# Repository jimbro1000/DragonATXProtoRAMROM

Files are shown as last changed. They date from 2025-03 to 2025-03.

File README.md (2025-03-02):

# Dragon 32 ATX Prototype RAM and ROM

This repository contains the KiCad project files
to produce the RAM and ROM component board for my
ATX Prototype backplane.

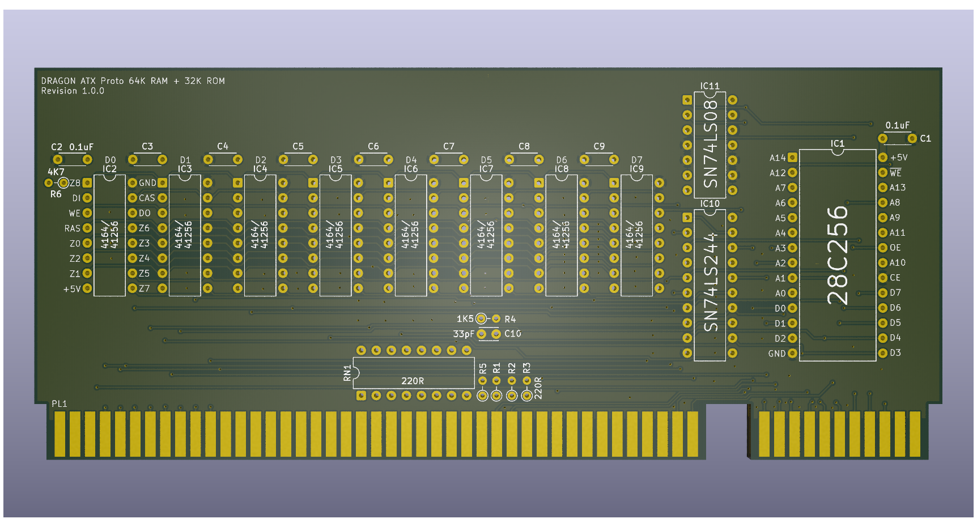
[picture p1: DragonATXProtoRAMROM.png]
Render of PCB top


This design requires the ATX backplane board in order 
to operate
See https://github.com/jimbro1000/DragonATXProto

## Notes

Revision 1 of the board contains a design using 
conventional DRAM, either 64k or 256k. Revision 2 will 
use SRAM.

Revision 3 will contain just a Flash ROM for use with
the FPGA board on the backplane as this carries a
large volume of RAM onboard.

This design has been completed using KiCad 9. Earlier
versions of KiCad are not compatible.

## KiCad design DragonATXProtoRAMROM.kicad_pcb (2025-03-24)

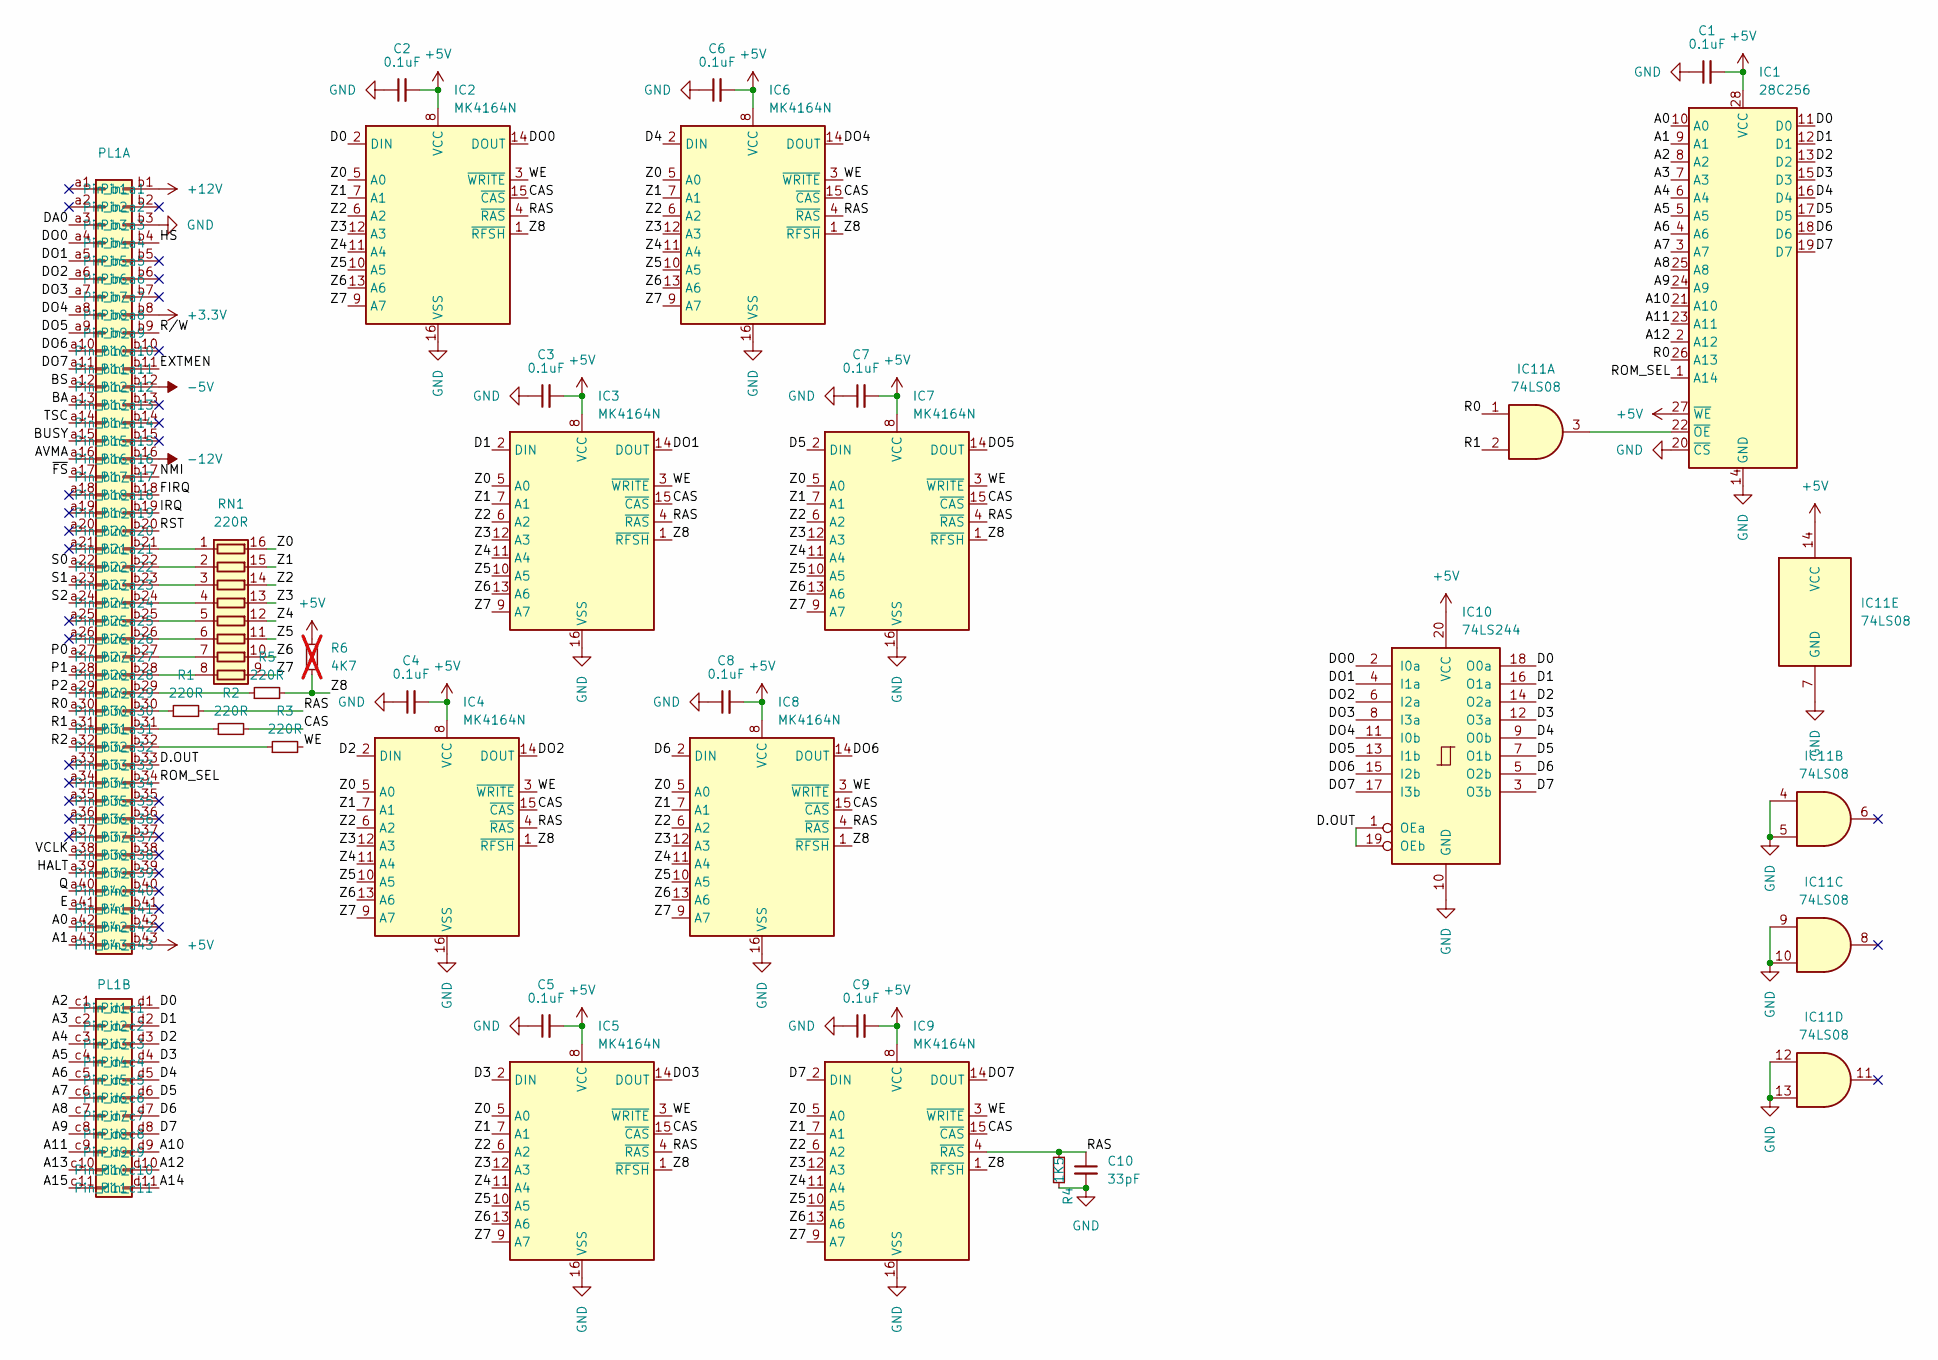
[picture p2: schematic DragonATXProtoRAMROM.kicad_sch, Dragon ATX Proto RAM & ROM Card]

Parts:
C1, C2, C3, C4, C5, C6, C7, C8, C9: 0.1uF; C_Disc_D4.3mm_W1.9mm_P5.00mm; DigiKey BC1101CT-ND
C10: 33pF; C_Disc_D3.0mm_W2.0mm_P2.50mm; DigiKey BC1007CT-ND
IC1: 28C256; DIP-28_W15.24mm
IC2, IC3, IC4, IC5, IC6, IC7, IC8, IC9: MK4164N; DIP-16_W7.62mm
IC10: 74LS244; DIP-20_W7.62mm
IC11: 74LS08; DIP-14_W7.62mm
PL1: Card_Edge
R1, R2, R3, R5: 220R; R_Axial_DIN0204_L3.6mm_D1.6mm_P2.54mm_Vertical
R4: 1K5; R_Axial_DIN0204_L3.6mm_D1.6mm_P2.54mm_Vertical; DigiKey CF14JT1K50CT-ND
R6: 4K7; R_Axial_DIN0204_L3.6mm_D1.6mm_P2.54mm_Vertical; not fitted
RN1: 220R; DIP-16_W7.62mm

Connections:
+3.3V: PL1.b8
+5V: C1.2, C2.2, C3.2, C4.2, C5.2, C6.2, C7.2, C8.2, C9.2, IC1.27 (~WE), IC1.28 (VCC), IC2.8 (VCC), IC3.8 (VCC), IC4.8 (VCC), IC5.8 (VCC), IC6.8 (VCC), IC7.8 (VCC), IC8.8 (VCC), IC9.8 (VCC), IC10.20 (VCC), IC11.14 (VCC), PL1.b43, R6.2
+12V: PL1.b1
-5V: PL1.b12
-12V: PL1.b16
/A0: IC1.10 (A0), PL1.a42
/A1: IC1.9 (A1), PL1.a43
/A2: IC1.8 (A2), PL1.c1
/A3: IC1.7 (A3), PL1.c2
/A4: IC1.6 (A4), PL1.c3
/A5: IC1.5 (A5), PL1.c4
/A6: IC1.4 (A6), PL1.c5
/A7: IC1.3 (A7), PL1.c6
/A8: IC1.25 (A8), PL1.c7
/A9: IC1.24 (A9), PL1.c8
/A10: IC1.21 (A10), PL1.d9
/A11: IC1.23 (A11), PL1.c9
/A12: IC1.2 (A12), PL1.d10
/A13: PL1.c10
/A14: PL1.d11
/A15: PL1.c11
/AVMA: PL1.a16
/BA: PL1.a13
/BS: PL1.a12
/BUSY: PL1.a15
/CAS: IC2.15 (~CAS), IC3.15 (~CAS), IC4.15 (~CAS), IC5.15 (~CAS), IC6.15 (~CAS), IC7.15 (~CAS), IC8.15 (~CAS), IC9.15 (~CAS), R2.2
/D0: IC1.11 (D0), IC2.2 (DIN), IC10.18 (O0a), PL1.d1
/D1: IC1.12 (D1), IC3.2 (DIN), IC10.16 (O1a), PL1.d2
/D2: IC1.13 (D2), IC4.2 (DIN), IC10.14 (O2a), PL1.d3
/D3: IC1.15 (D3), IC5.2 (DIN), IC10.12 (O3a), PL1.d4
/D4: IC1.16 (D4), IC6.2 (DIN), IC10.9 (O0b), PL1.d5
/D5: IC1.17 (D5), IC7.2 (DIN), IC10.7 (O1b), PL1.d6
/D6: IC1.18 (D6), IC8.2 (DIN), IC10.5 (O2b), PL1.d7
/D7: IC1.19 (D7), IC9.2 (DIN), IC10.3 (O3b), PL1.d8
/D.OUT: IC10.1 (OEa), IC10.19 (OEb), PL1.b33
/DA0: PL1.a3
/DO0: IC2.14 (DOUT), IC10.2 (I0a), PL1.a4
/DO1: IC3.14 (DOUT), IC10.4 (I1a), PL1.a5
/DO2: IC4.14 (DOUT), IC10.6 (I2a), PL1.a6
/DO3: IC5.14 (DOUT), IC10.8 (I3a), PL1.a7
/DO4: IC6.14 (DOUT), IC10.11 (I0b), PL1.a8
/DO5: IC7.14 (DOUT), IC10.13 (I1b), PL1.a9
/DO6: IC8.14 (DOUT), IC10.15 (I2b), PL1.a10
/DO7: IC9.14 (DOUT), IC10.17 (I3b), PL1.a11
/E: PL1.a41
/EXTMEN: PL1.b11
/FIRQ: PL1.b18
/HALT: PL1.a39
/HS: PL1.b4
/IRQ: PL1.b19
/NMI: PL1.b17
/P0: PL1.a27
/P1: PL1.a28
/P2: PL1.a29
/Q: PL1.a40
/R0: IC1.26 (A13), IC11.1, PL1.a30
/R1: IC11.2, PL1.a31
/R2: PL1.a32
/RAS: C10.1, IC2.4 (~RAS), IC3.4 (~RAS), IC4.4 (~RAS), IC5.4 (~RAS), IC6.4 (~RAS), IC7.4 (~RAS), IC8.4 (~RAS), IC9.4 (~RAS), R1.2, R4.2
/ROM_SEL: IC1.1 (A14), PL1.b34
/RST: PL1.b20
/R/W: PL1.b9
/S0: PL1.a22
/S1: PL1.a23
/S2: PL1.a24
/TSC: PL1.a14
/VCLK: PL1.a38
/WE: IC2.3 (~WRITE), IC3.3 (~WRITE), IC4.3 (~WRITE), IC5.3 (~WRITE), IC6.3 (~WRITE), IC7.3 (~WRITE), IC8.3 (~WRITE), IC9.3 (~WRITE), R3.2
/Z0: IC2.5 (A0), IC3.5 (A0), IC4.5 (A0), IC5.5 (A0), IC6.5 (A0), IC7.5 (A0), IC8.5 (A0), IC9.5 (A0), RN1.16 (R1.2)
/Z1: IC2.7 (A1), IC3.7 (A1), IC4.7 (A1), IC5.7 (A1), IC6.7 (A1), IC7.7 (A1), IC8.7 (A1), IC9.7 (A1), RN1.15 (R2.2)
/Z2: IC2.6 (A2), IC3.6 (A2), IC4.6 (A2), IC5.6 (A2), IC6.6 (A2), IC7.6 (A2), IC8.6 (A2), IC9.6 (A2), RN1.14 (R3.2)
/Z3: IC2.12 (A3), IC3.12 (A3), IC4.12 (A3), IC5.12 (A3), IC6.12 (A3), IC7.12 (A3), IC8.12 (A3), IC9.12 (A3), RN1.13 (R4.2)
/Z4: IC2.11 (A4), IC3.11 (A4), IC4.11 (A4), IC5.11 (A4), IC6.11 (A4), IC7.11 (A4), IC8.11 (A4), IC9.11 (A4), RN1.12 (R5.2)
/Z5: IC2.10 (A5), IC3.10 (A5), IC4.10 (A5), IC5.10 (A5), IC6.10 (A5), IC7.10 (A5), IC8.10 (A5), IC9.10 (A5), RN1.11 (R6.2)
/Z6: IC2.13 (A6), IC3.13 (A6), IC4.13 (A6), IC5.13 (A6), IC6.13 (A6), IC7.13 (A6), IC8.13 (A6), IC9.13 (A6), RN1.10 (R7.2)
/Z7: IC2.9 (A7), IC3.9 (A7), IC4.9 (A7), IC5.9 (A7), IC6.9 (A7), IC7.9 (A7), IC8.9 (A7), IC9.9 (A7), RN1.9 (R8.2)
/Z8: IC2.1 (~RFSH), IC3.1 (~RFSH), IC4.1 (~RFSH), IC5.1 (~RFSH), IC6.1 (~RFSH), IC7.1 (~RFSH), IC8.1 (~RFSH), IC9.1 (~RFSH), R5.2, R6.1
/~FS: PL1.a17
GND: C1.1, C2.1, C3.1, C4.1, C5.1, C6.1, C7.1, C8.1, C9.1, C10.2, IC1.14 (GND), IC1.20 (~CS), IC2.16 (VSS), IC3.16 (VSS), IC4.16 (VSS), IC5.16 (VSS), IC6.16 (VSS), IC7.16 (VSS), IC8.16 (VSS), IC9.16 (VSS), IC10.10 (GND), IC11.4, IC11.5, IC11.7 (GND), IC11.9, IC11.10, IC11.12, IC11.13, PL1.b3, R4.1
unnamed: IC1.22 (~OE), IC11.3
unnamed: PL1.b21, RN1.1 (R1.1)
unnamed: PL1.b22, RN1.2 (R2.1)
unnamed: PL1.b23, RN1.3 (R3.1)
unnamed: PL1.b24, RN1.4 (R4.1)
unnamed: PL1.b25, RN1.5 (R5.1)
unnamed: PL1.b26, RN1.6 (R6.1)
unnamed: PL1.b27, RN1.7 (R7.1)
unnamed: PL1.b28, RN1.8 (R8.1)
unnamed: PL1.b29, R5.1
unnamed: PL1.b30, R1.1
unnamed: PL1.b31, R2.1
unnamed: PL1.b32, R3.1

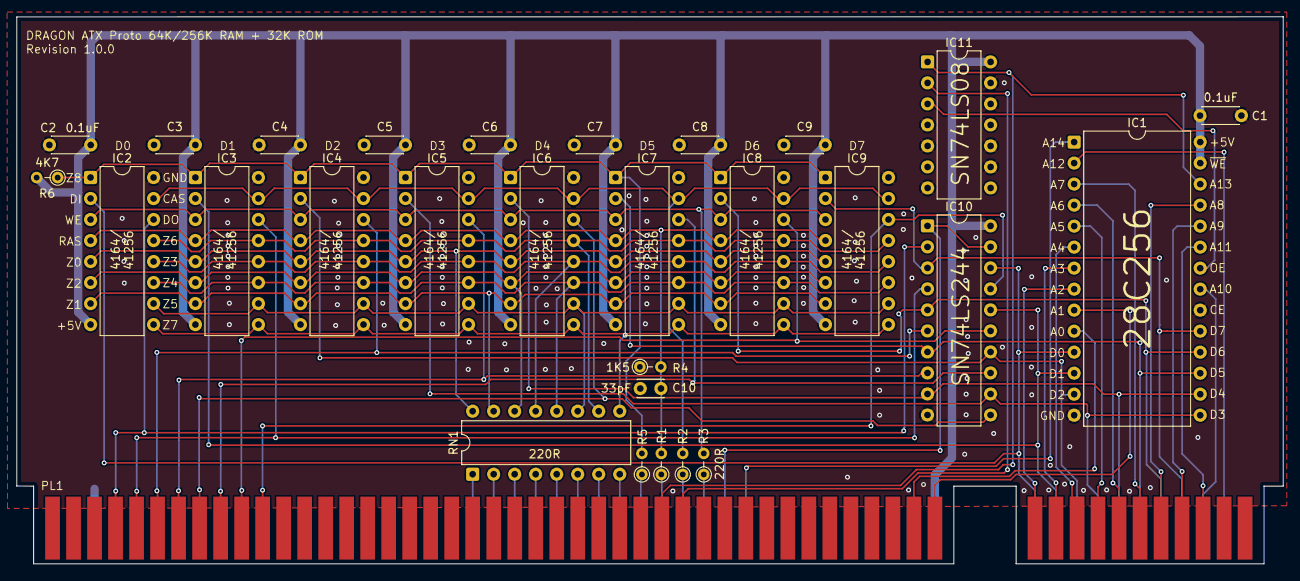
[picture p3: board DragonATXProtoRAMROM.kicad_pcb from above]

Board: 2 copper layers, 153.1 x 66.1 mm, 29 parts (0 on the bottom side), 60 nets.

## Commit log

2025-03-17 update card edge spec
    [DragonATXProtoRAMROM.kicad_pcb]
2025-03-24 fix missing gnd pin connection
    [DragonATXProtoRAMROM.kicad_pcb, DragonATXProtoRAMROM.kicad_sch]
